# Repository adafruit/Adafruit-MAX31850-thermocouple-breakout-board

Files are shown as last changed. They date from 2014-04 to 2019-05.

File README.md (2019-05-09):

# PCB files for Adafruit MAX31850 1-Wire Thermocouple Breakout Board

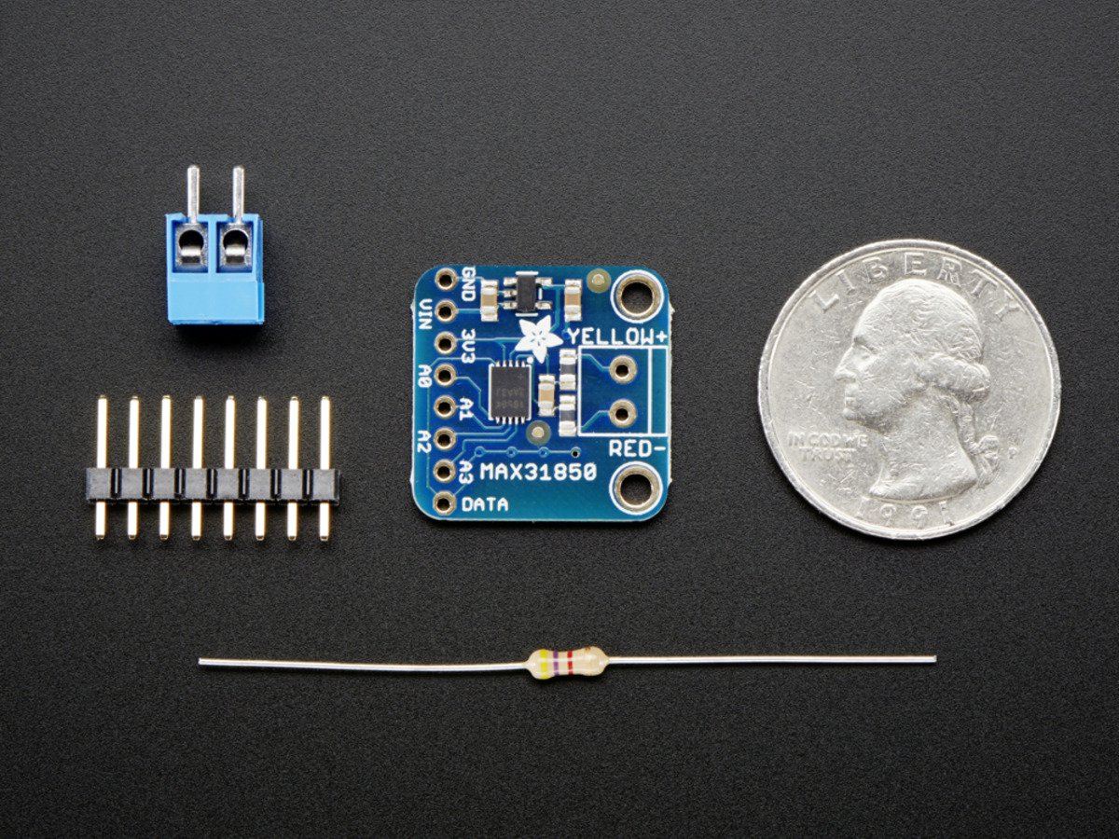
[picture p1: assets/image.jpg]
<a href="http://www.adafruit.com/products/1727"><br/>Click here to purchase one from the Adafruit shop</a>

Thermocouples are very sensitive, requiring a good amplifier with a cold-compensation reference. [So far we've carried the very nice MAX31855 which is an SPI interface thermocouple amplifier](https://www.adafruit.com/products/269). The '855 is great but if you have a lot of thermocouples to measure it isn't terribly easy to use. That's why we are also carrying the new '850 model from Maxim - it's a "1-Wire" thermocouple amp which can have any number of breakouts on a single shared I/O line.

The MAX31850K does everything for you, and can be easily interfaced with any microcontroller that has 1-Wire support. This breakout board has the chip itself, a 3.3V regulator with 10uF bypass capacitors all assembled and tested. This board can be used with 'parasitic power' - where the power is on the data line - or with 'local power' where the power for the converter comes in on the Vin Pin.

Please note: this board does not have level shifting on the 3V Data line - we did this on purpose so that it can be used in parasitic mode. The data line must be level shifted to [3V - our 4-channel shifter works wonderfully for level shifting 1-Wire](http://www.adafruit.com/products/757) and you only need one at the '1-Wire host' for all thermocouples on the shared data line.

The MAX31850K data format is very similar to that of the well known 1-Wire DS18B20 temp sensor but it is not drop in compatible without code changes to check for the new '1 Wire family' type. We have adapted the classic Arduino [OneWire](https://github.com/adafruit/MAX31850_OneWire) and [DallasTemp](https://github.com/adafruit/MAX31850_DallasTemp) libraries to be MAX31850 compatible, so please click on those links to grab our libraries.

Comes with a 2 pin terminal block (for connecting to the thermocouple), 4.7K data line pullup resistor, and pin header (to plug into any breadboard or perfboard).
[Goes great with our 1m K-type thermocouple](http://www.adafruit.com/products/270). Not for use with any other kind of thermocouple, K type only!<Paste>

- Works with any K type thermocouple
- Will not work with any other kind of thermocouple other than K type
- -270C to +1370C output in 0.25 degree increments
- Internal temperature reading
- 3.3 to 5v power supply. Data line is 3V only
- 1-Wire interface allows any number of thermocouple amps on a single data line

Note: The terminal block included with your product may be blue or black.

## License

Adafruit invests time and resources providing this open source design, 
please support Adafruit and open-source hardware by purchasing 
products from Adafruit!

Designed by Limor Fried/Ladyada for Adafruit Industries.
Creative Commons Attribution/Share-Alike, all text above must be included in any redistribution
All text above must be included in any redistribution

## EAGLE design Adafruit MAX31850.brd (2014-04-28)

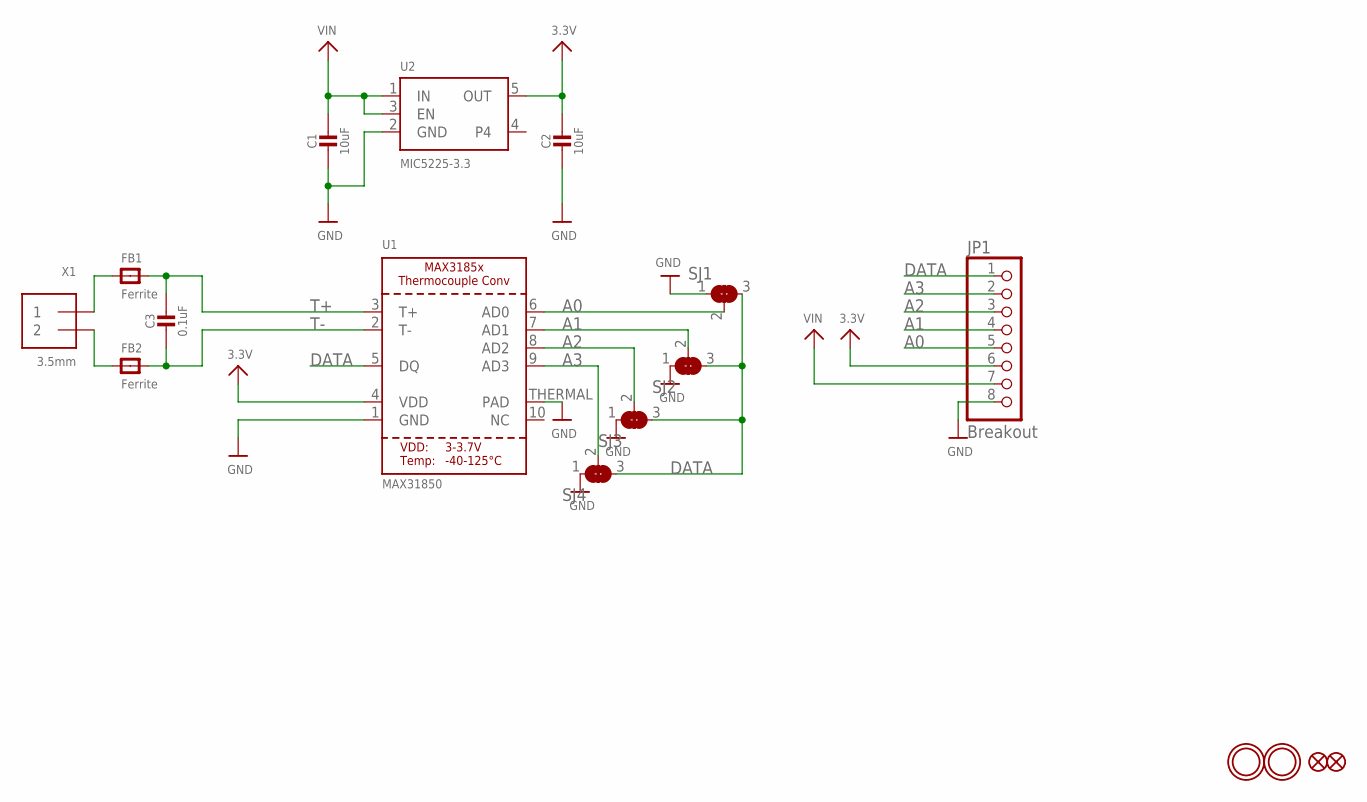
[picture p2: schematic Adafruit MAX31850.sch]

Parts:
C1, C2: 10uF; 0805-NO
C3: 0.1uF; 0805-NO
FB1, FB2: Ferrite; 0805
FID1, FID2: FIDUCIAL""; FIDUCIAL_1MM
JP1: Breakout; 1X08_ROUND_70
SJ1, SJ2, SJ3, SJ4: SOLDERJUMPER_2WAY; SOLDERJUMPER_2WAY_OPEN_NOPASTE
U1: MAX31850; TDFN10_3X4MM
U2: MIC5225-3.3; SOT23-5
U$8, U$9: MOUNTINGHOLE2.5; MOUNTINGHOLE_2.5_PLATED
X1: 3.5mm; TERMBLOCK_1X2-3.5MM

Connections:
3.3V: C2.1, JP1.6, U1.4 (VDD), U2.5 (OUT)
A0: JP1.5, SJ1.2, U1.6 (AD0)
A1: JP1.4, SJ2.2, U1.7 (AD1)
A2: JP1.3, SJ3.2, U1.8 (AD2)
A3: JP1.2, SJ4.2, U1.9 (AD3)
DATA: JP1.1, SJ1.3, SJ2.3, SJ3.3, SJ4.3, U1.5 (DQ)
GND: C1.2, C2.2, JP1.8, SJ1.1, SJ2.1, SJ3.1, SJ4.1, U1.1 (GND), U1.THERMAL (PAD), U2.2 (GND)
unnamed: FB1.1, X1.1
unnamed: FB2.1, X1.2
T+: C3.1, FB1.2, U1.3 (T+)
T-: C3.2, FB2.2, U1.2 (T-)
VIN: C1.1, JP1.7, U2.1 (IN), U2.3 (EN)

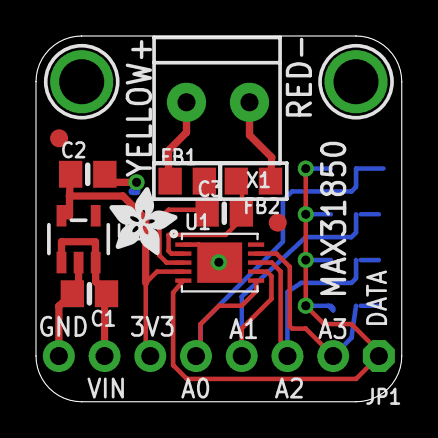
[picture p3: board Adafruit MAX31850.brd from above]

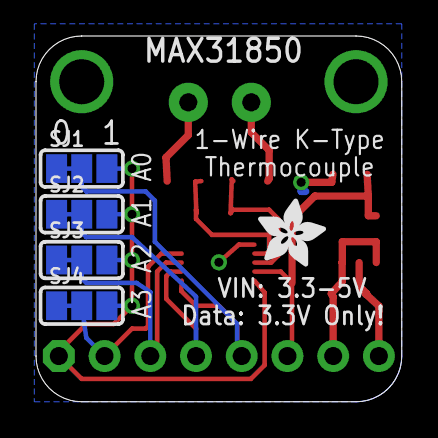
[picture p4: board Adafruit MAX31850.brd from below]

Board: 2 copper layers, 20.3 x 20.3 mm, 19 parts (5 on the bottom side), 12 nets.

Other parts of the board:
U$18, U$19: ADAFRUIT_3.5MM

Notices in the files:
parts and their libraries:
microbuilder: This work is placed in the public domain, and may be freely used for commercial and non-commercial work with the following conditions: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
